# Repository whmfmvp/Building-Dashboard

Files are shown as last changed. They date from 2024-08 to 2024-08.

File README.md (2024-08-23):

<h1>Move to Net Zero: A Physical Dashboard for Net Zero Carbon Buildings</h1>  
<div align="center">
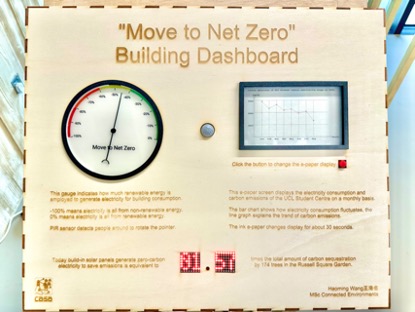
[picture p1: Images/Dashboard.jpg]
Dashboard Image

<p>Figure 1. Physical Building Dashboard</p>
</div>

<h2>Introduction</h2>
At the 2015 United Nations Climate Conference, 195 countries committed to the Paris Agreement's climate target, aiming for net zero carbon emissions. Buildings contribute significantly to global carbon emissions, making Net Zero Carbon Buildings (NZCB) a critical area in achieving this target. To raise public awareness of the importance of NZCB and to help users understand the journey toward achieving net zero in buildings, this project introduces the "Move to Net Zero" physical building dashboard.  

This dashboard serves as an interactive tool to promote the concept of NZCB, encouraging users to engage in daily actions that reduce carbon emissions. By leveraging IoT technology, the dashboard provides real-time data on electricity consumption, carbon emissions, and solar energy usage, offering users valuable insights into the building's environmental impact.  

<h2>Research Question</h2>  
This project seeks to answer the question: How can a physical dashboard displaying real-time data related to carbon neutrality effectively enhance communication and foster net-zero practices among the general public?  

<h2>Key Features</h2>   
<div align="center">
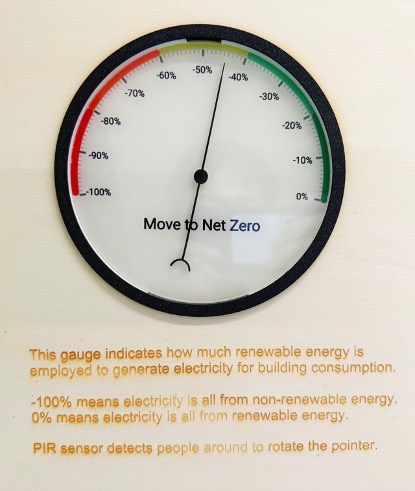
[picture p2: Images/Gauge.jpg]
Gauge Image

<p>Figure 2. Gauge</p>
</div>  

1. Real-time Data Visualization: The dashboard showcases the building's contribution to the environment, focusing on electricity consumption, carbon emissions, and solar energy usage.  
<div align="center">
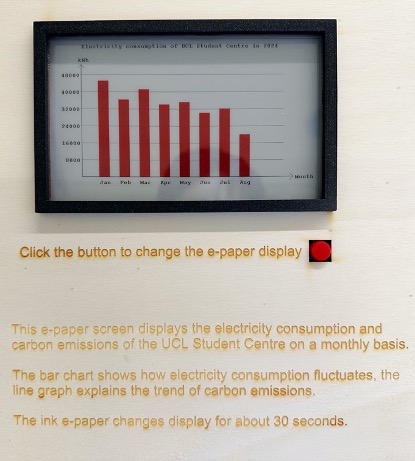
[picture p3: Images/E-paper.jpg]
E-paper Image

<p>Figure 3. E-paper</p>
</div>  

2. Interactive Design: Equipped with PIR sensors and buttons, the dashboard interacts with users by sensing their movements and actions.  
  
<div align="center">
Dot_matrix module Image
<p>Figure 4. Dot_matrix module</p>
</div>  

3. Data Visualization Tools: The dashboard utilizes gauge displays, e-paper, and a dot matrix module to communicate information in an accessible and engaging manner.  
IoT Integration: The system is powered by ESP32 microcontrollers, ensuring efficient data processing and real-time updates.  

<h2>Case Study: UCL Student Centre</h2>  
The project includes a case study of the UCL Student Centre, analyzing its electricity consumption and carbon emissions over the past two years. The findings indicate significant progress toward NZCB, with nearly 50% of the building's electricity now sourced from renewable energy.  

<h2>User Feedback</h2>  
A survey of 32 users who interacted with the dashboard revealed that the device successfully communicates key information about the building's energy usage and carbon footprint. However, it also highlighted the need for more intuitive content presentation to make the data easier to understand.  

<h2>Future Work</h2>  
Future iterations of the "Move to Net Zero" dashboard will focus on:  

1. Enriching Energy Information: Providing more comprehensive data about the building's energy use.  

2. Improving User Experience: Simplifying the dashboard's interface to make it more user-friendly and accessible.  
   
3. Add ultrasonic sensors: Counting users more precisely and collect avarage usage time for further research.

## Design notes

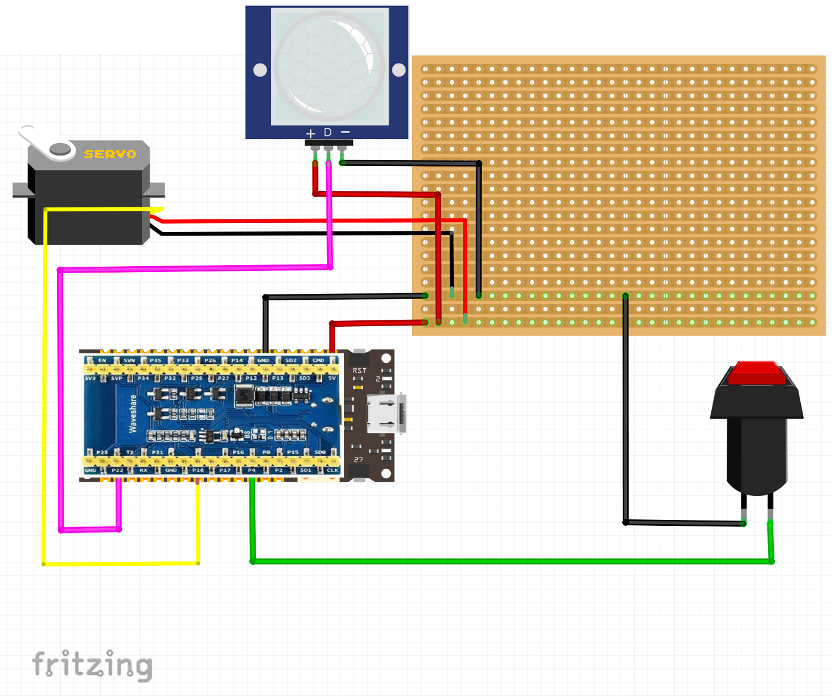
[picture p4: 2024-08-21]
Schematic/ESP32_1_back.png

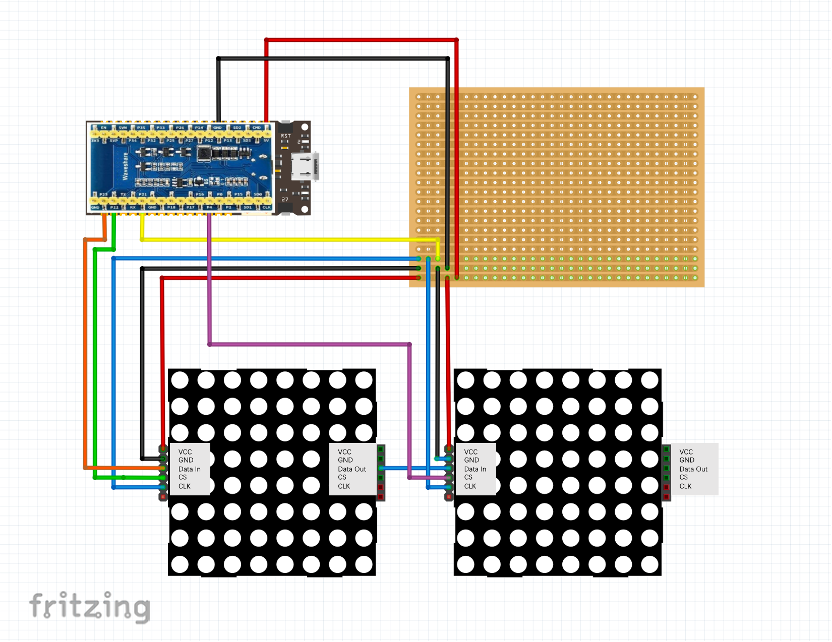
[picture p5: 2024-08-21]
Schematic/ESP32_2.png

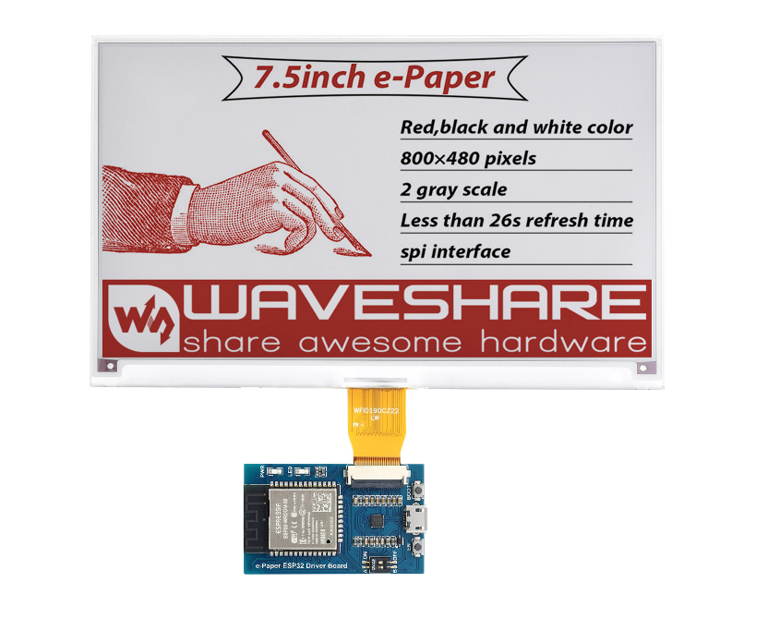
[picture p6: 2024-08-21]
Schematic/ESP32_1_front.png

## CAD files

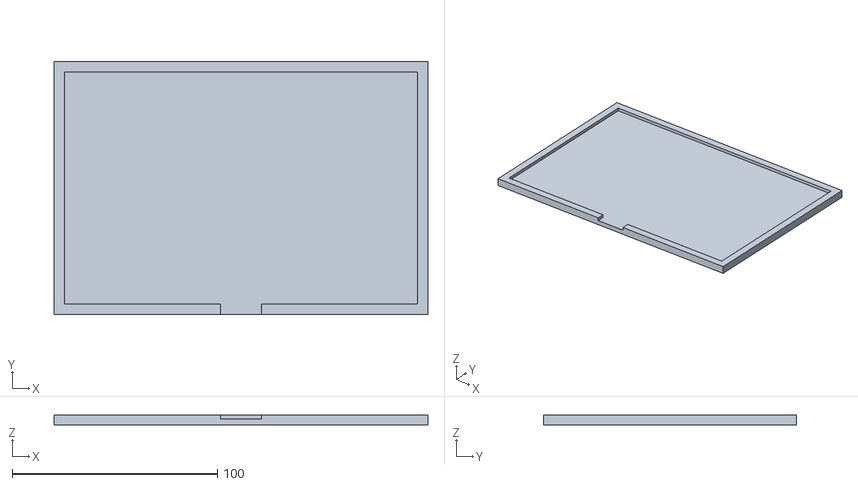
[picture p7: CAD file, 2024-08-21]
3D print/E-paper-back-frame.stl
182.2 x 123.2 x 5.00

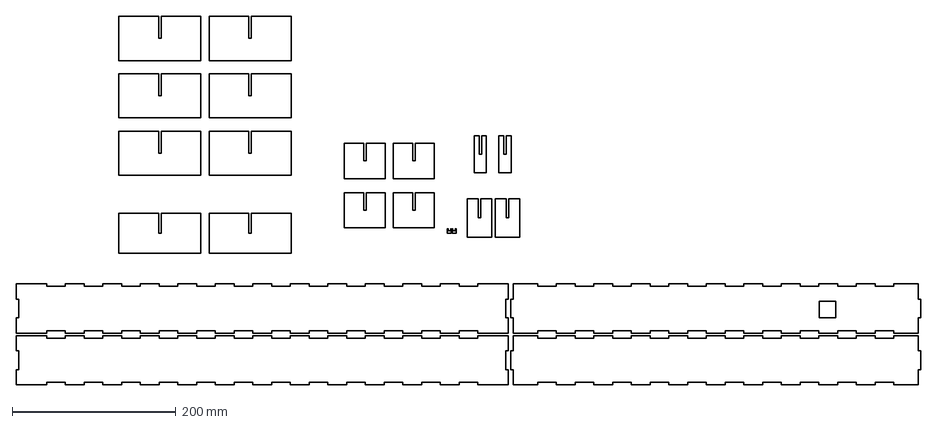
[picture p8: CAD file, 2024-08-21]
Laser cut/Underprop in the enclosure.dxf
1103.0 x 449.5 mm

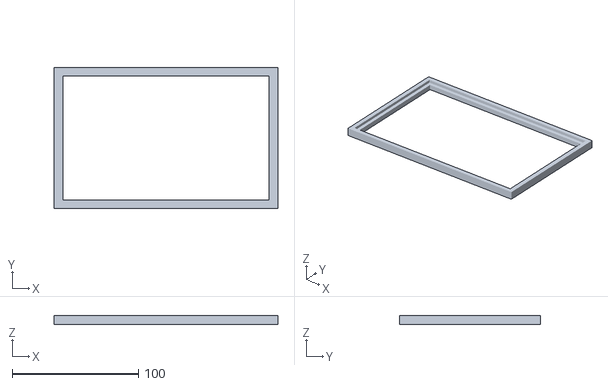
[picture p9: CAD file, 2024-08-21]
3D print/E-paper-front-frame.stl
177.2 x 111.9 x 7.00

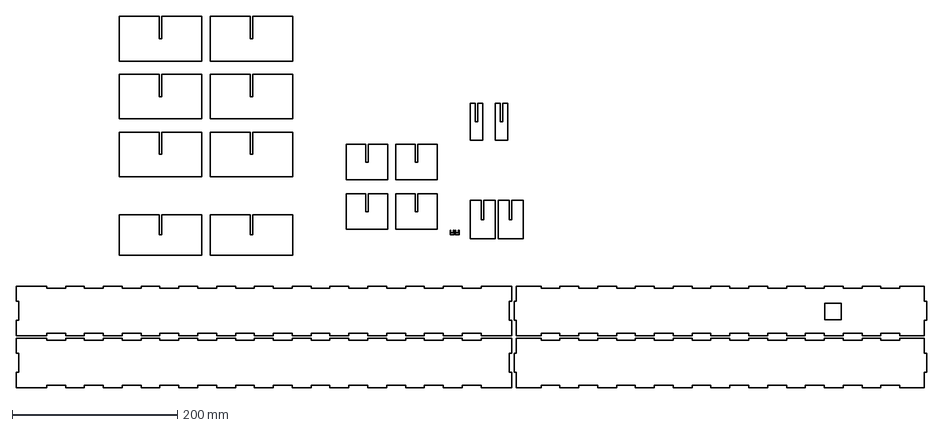
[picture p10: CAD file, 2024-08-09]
Laser cut/underprop.dxf
1103.0 x 449.5 mm

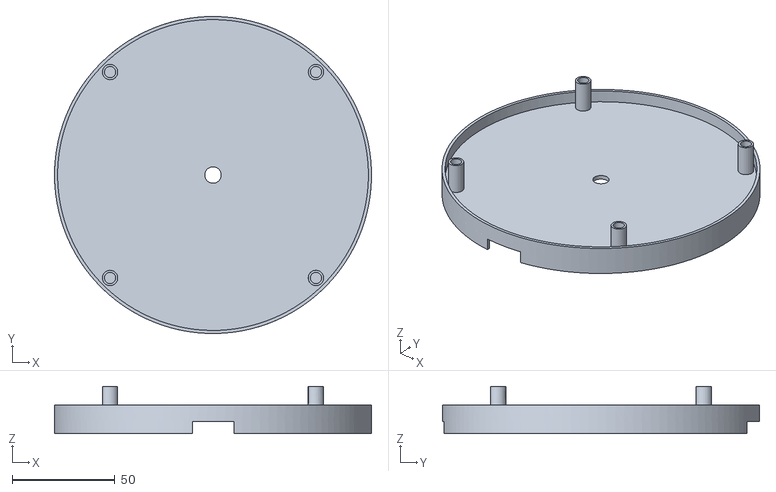
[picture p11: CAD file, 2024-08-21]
3D print/Gauge_middle.stl
154.0 x 154.0 x 23.0

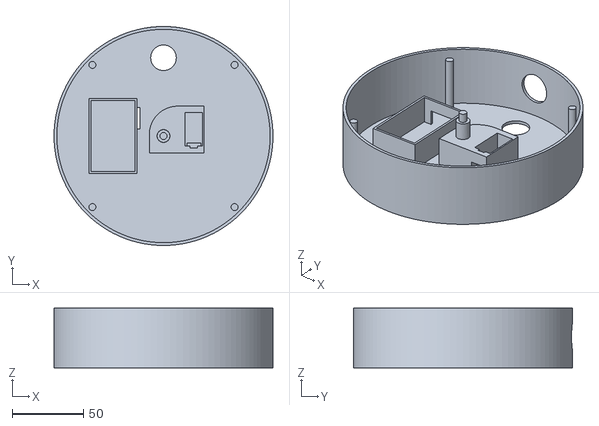
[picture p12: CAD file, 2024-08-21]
3D print/Gauge_house.stl
154.0 x 154.0 x 42.0

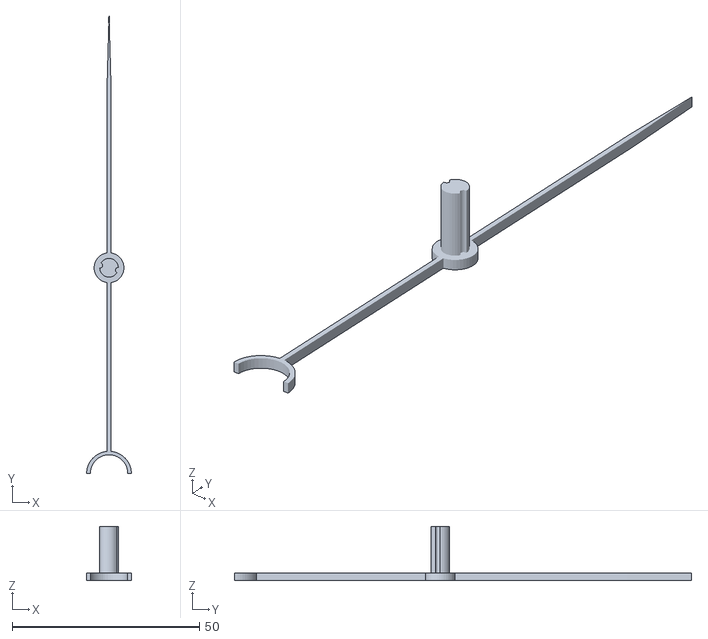
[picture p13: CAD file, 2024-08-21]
3D print/Pointer.stl
12.0 x 122.2 x 14.5

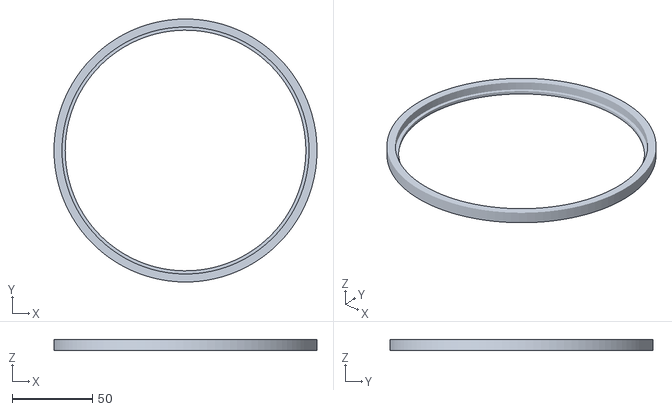
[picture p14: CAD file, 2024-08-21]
3D print/Gauge_top.stl
164.0 x 164.0 x 7.00

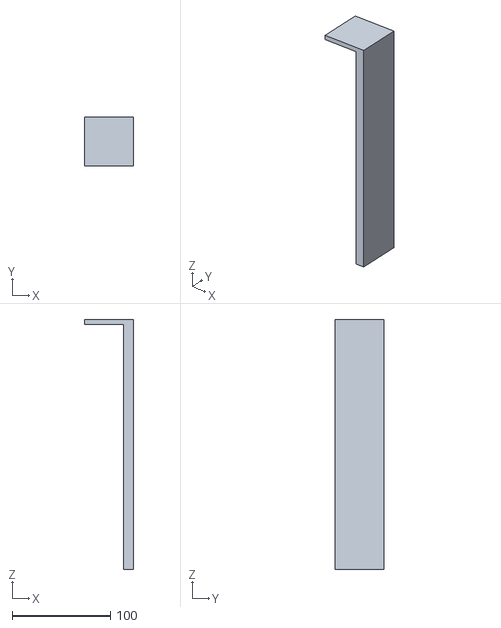
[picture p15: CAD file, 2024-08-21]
3D print/Support in the enclosure.stl
50.0 x 50.0 x 255.0

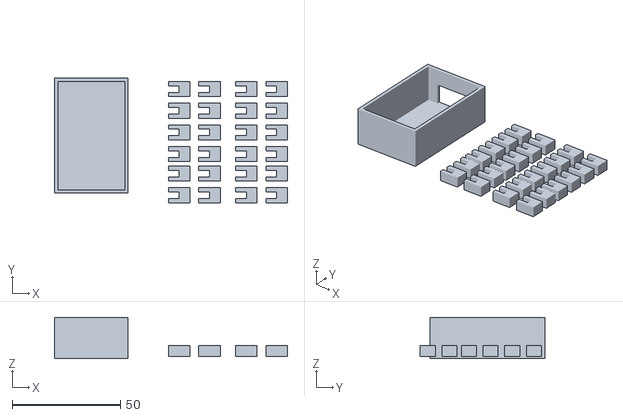
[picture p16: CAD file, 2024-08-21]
3D print/ESP32 house.stl
107.5 x 57.5 x 19.0

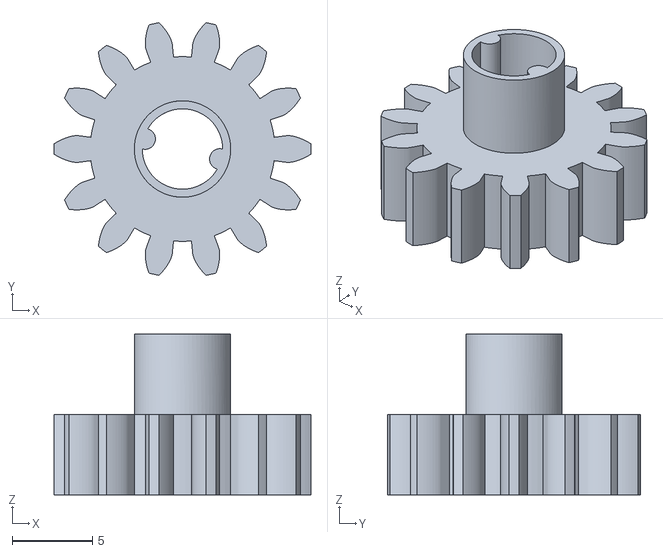
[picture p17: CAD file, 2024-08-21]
3D print/Small gear.stl
16.0 x 15.7 x 10.0

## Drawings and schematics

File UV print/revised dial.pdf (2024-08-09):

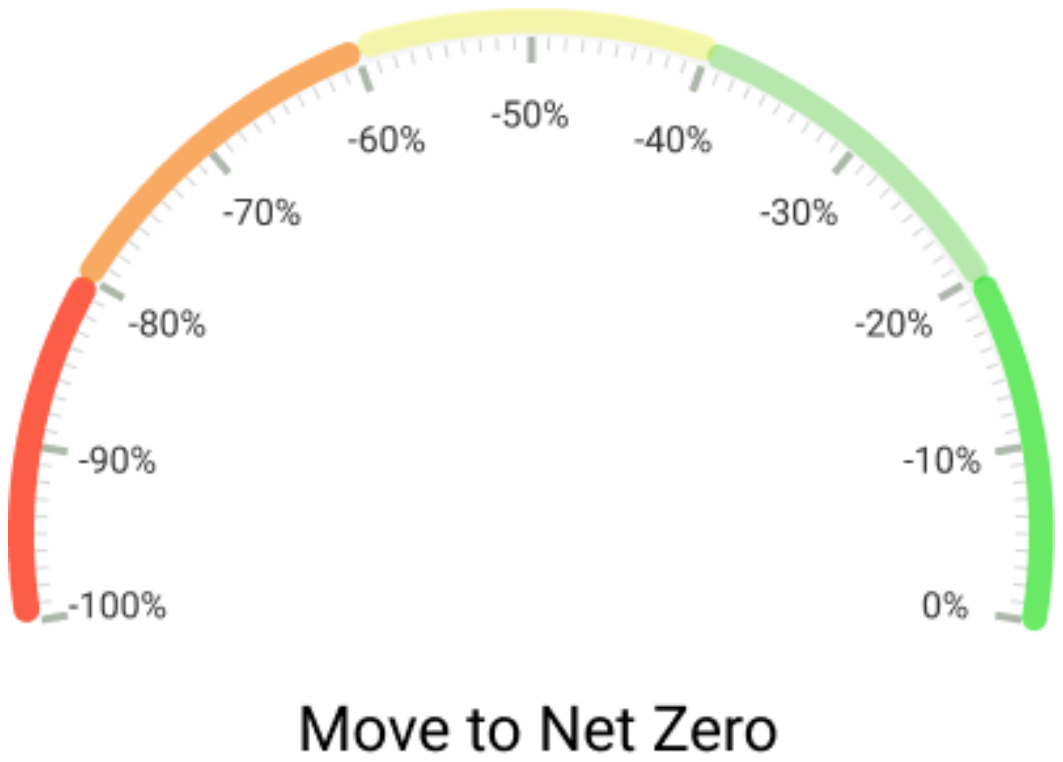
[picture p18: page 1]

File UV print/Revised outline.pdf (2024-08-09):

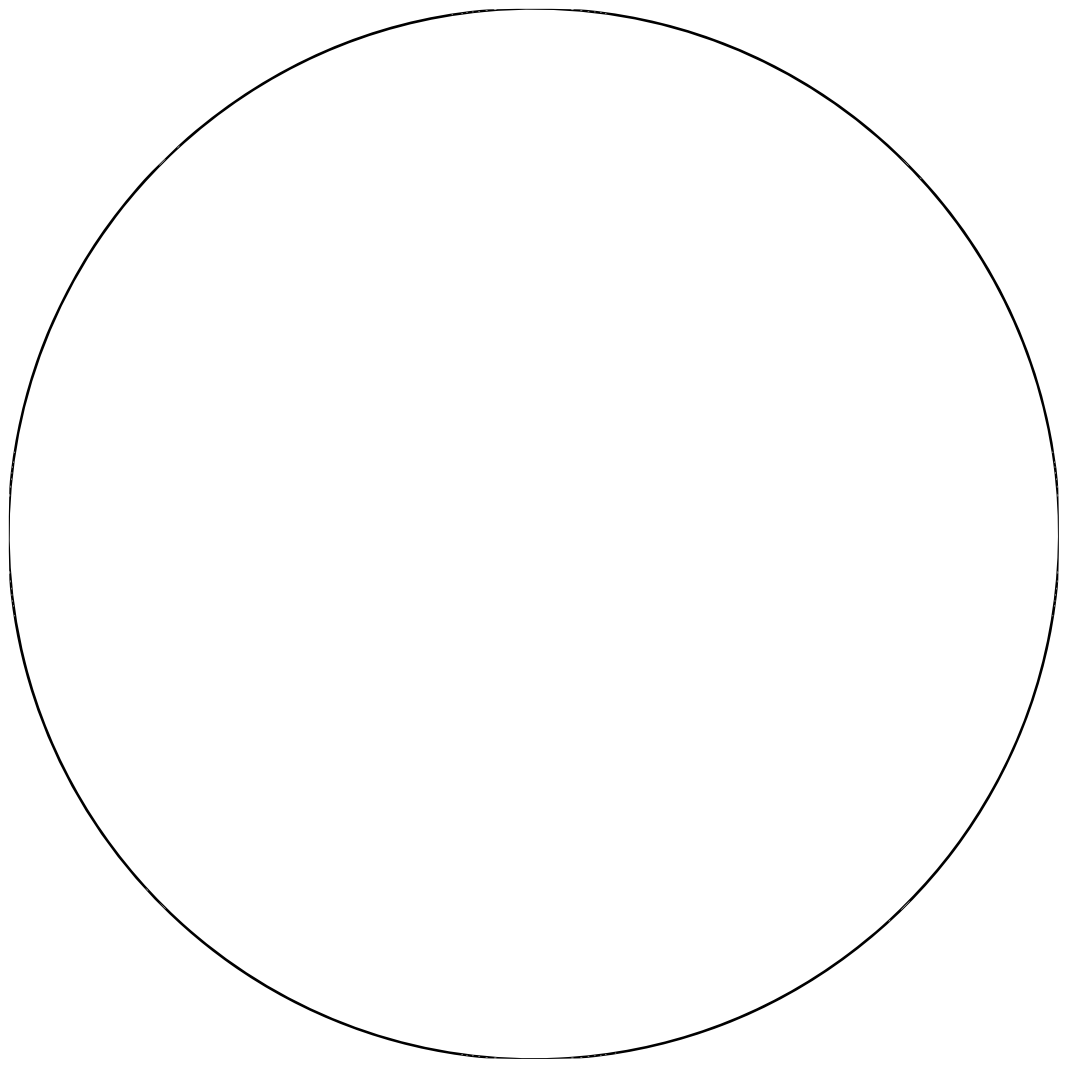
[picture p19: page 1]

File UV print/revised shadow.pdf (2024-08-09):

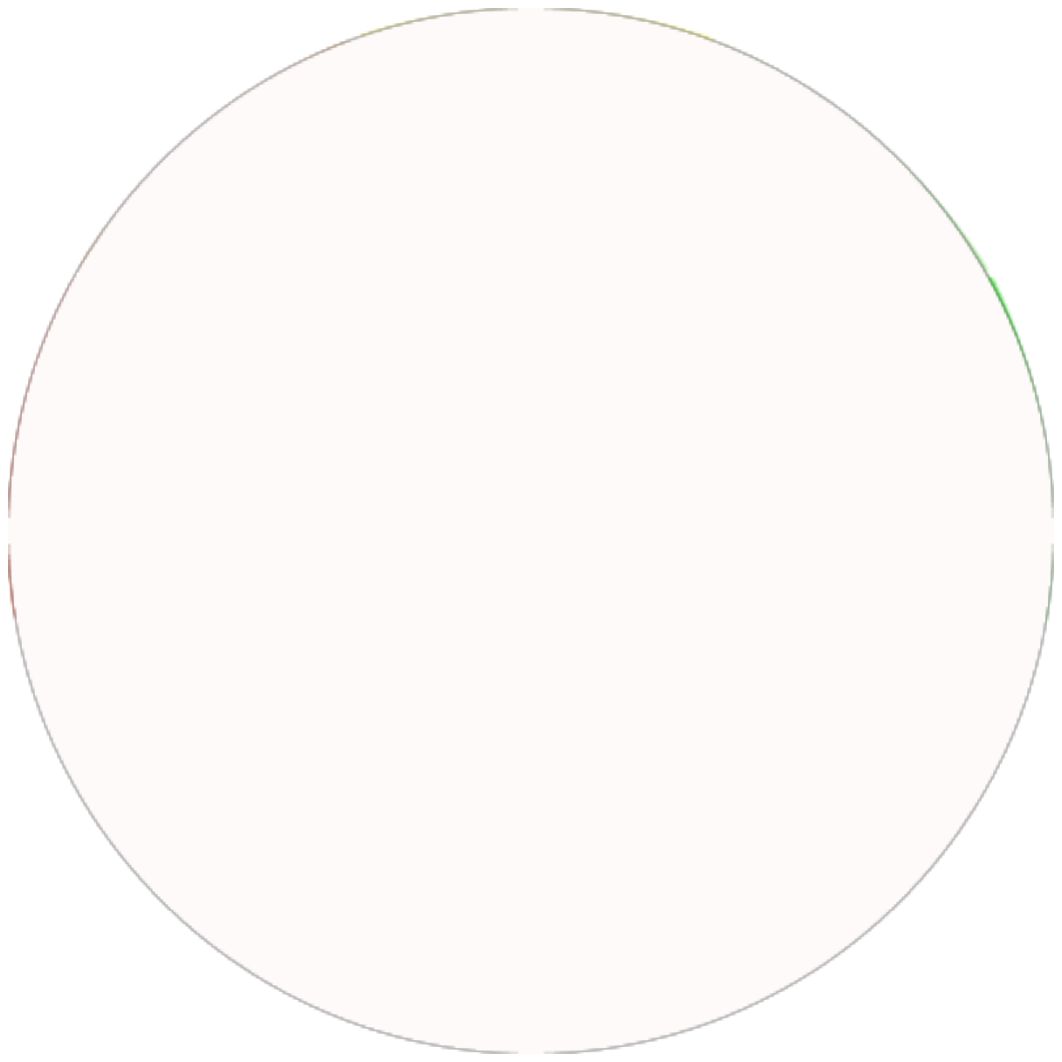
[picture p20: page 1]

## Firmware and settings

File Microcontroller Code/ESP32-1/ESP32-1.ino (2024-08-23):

#include <WiFi.h>
#include <PubSubClient.h>
#include "DEV_Config.h"
#include "EPD.h"
#include "GUI_Paint.h"
#include "imagedata.h"
#include <stdlib.h>
#include <ESP32Servo.h>
#include <NTPClient.h>
#include <WiFiUdp.h>

// Wi-Fi credentials
const char* ssid = "YOUR_WIFI";
const char* password = "YOUR_PASSWORD";

// MQTT broker parameters
const char* mqtt_server = "YOUR_MQTT";
const int mqtt_port = 1884;
const char* mqtt_username = "-";
const char* mqtt_password = "-";
const char* mqtt_topic_base_electricity = "student/CASA0022/zczqhw8/Electricity/";
const char* mqtt_topic_base_carbon = "student/CASA0022/zczqhw8/Carbon_Emissions/";
const char* mqtt_topic_servo = "student/CASA0022/zczqhw8/Net_zero_ratio"; 
const char* mqtt_topic_pir = "student/CASA0022/zczqhw8/PIR"; 
const char* mqtt_topic_button = "student/CASA0022/zczqhw8/Button";


WiFiClient espClient;
PubSubClient client(espClient);
Servo servoMotor;

int yCoordsElectricity[8] = {400, 400, 400, 400, 400, 400, 400, 400};
int yCoordsCarbon[8] = {400, 400, 400, 400, 400, 400, 400, 400};
bool dataReceivedElectricity[8] = {false, false, false, false, false, false, false, false};
bool dataReceivedCarbon[8] = {false, false, false, false, false, false, false, false};

UBYTE *BlackImage, *RYImage;
bool updateDisplay = false;
int receivedCountElectricity = 0;
int receivedCountCarbon = 0;
bool displayBarChart = true; 

const int buttonPin = 4; 
const int servoPin = 18;
const int pirPin = 22;    
int targetServoAngle = 0; 
const int servoRestAngle = 0; 

unsigned long lastPIRCheck = 0;  
const long PIRInterval = 2000;   
bool servoActive = false;        
unsigned long servoActivationTime = 0;  

int servoTurnCount = 0;          
int buttonPressCount = 0;        
unsigned long lastMidnightCheck = 0; 

bool lastButtonState = HIGH;      
unsigned long lastDebounceTime = 0; 
const long debounceDelay = 50;    

// NTP Client
WiFiUDP ntpUDP;
NTPClient timeClient(ntpUDP, "pool.ntp.org", 0, 60000); 

void setup() {
  Serial.begin(115200);
  Serial.println("EPD_7IN5B_V2_test Demo");

  // Initialize Wi-Fi
  setup_wifi();

  // Initialize MQTT
  client.setServer(mqtt_server, mqtt_port);
  client.setCallback(mqtt_callback);

  // Initialize button
  pinMode(buttonPin, INPUT_PULLUP); 

  pinMode(pirPin, INPUT); 
  servoMotor.attach(servoPin); 

  // Initialize e-Paper display
  DEV_Module_Init();

  // Attach servo
  ESP32PWM::allocateTimer(0); 
  servoMotor.setPeriodHertz(50); 
  servoMotor.attach(servoPin, 500, 2400); 

    // Initialize NTP
  timeClient.begin();

  Serial.println("e-Paper Init and Clear...");
  EPD_7IN5B_V2_Init();
  EPD_7IN5B_V2_Clear();
  DEV_Delay_ms(500);

  // Create image cache
  UWORD Imagesize = ((EPD_7IN5B_V2_WIDTH % 8 == 0) ? (EPD_7IN5B_V2_WIDTH / 8) : (EPD_7IN5B_V2_WIDTH / 8 + 1)) * EPD_7IN5B_V2_HEIGHT;

  if ((BlackImage = (UBYTE *)malloc(Imagesize)) == NULL) {
    Serial.println("Failed to apply for black memory...");
    while(1);
  }
  if ((RYImage = (UBYTE *)malloc(Imagesize)) == NULL) {
    Serial.println("Failed to apply for red memory...");
    while(1);
  }
  Serial.println("NewImage: BlackImage and RYImage");
  Paint_NewImage(BlackImage, EPD_7IN5B_V2_WIDTH, EPD_7IN5B_V2_HEIGHT, 0, WHITE);
  Paint_NewImage(RYImage, EPD_7IN5B_V2_WIDTH, EPD_7IN5B_V2_HEIGHT, 0, WHITE);

  // Clear image cache
  Paint_SelectImage(BlackImage);
  Paint_Clear(WHITE);
  Paint_SelectImage(RYImage);
  Paint_Clear(WHITE);

  // Draw initial image
  drawImage(BlackImage, RYImage, displayBarChart);
}
void loop() {
  if (!client.connected()) {
    reconnect();
  }
  client.loop();

  unsigned long currentMillis = millis();
  timeClient.update(); 

  if (currentMillis - lastMidnightCheck >= 60000) {
    lastMidnightCheck = currentMillis;
    if (timeClient.getHours() == 0 && timeClient.getMinutes() == 0) {
      servoTurnCount = 0; 
      buttonPressCount = 0; 
      Serial.println("Servo turn count and button press count reset to 0 at midnight.");
    }
  }

  if (currentMillis - lastPIRCheck >= PIRInterval) {
    lastPIRCheck = currentMillis; 
    int pirState = digitalRead(pirPin);
    if (pirState == HIGH && !servoActive) {
      servoMotor.write(targetServoAngle);
      servoActivationTime = currentMillis;
      servoActive = true;
      servoTurnCount++; 
      client.publish(mqtt_topic_pir, String(servoTurnCount).c_str()); 
      Serial.print("Motion detected - Servo moving to target angle. Turn count: ");
      Serial.println(servoTurnCount);
    }
  }

  if (servoActive && (millis() - servoActivationTime >= 10000)) {
    servoMotor.write(servoRestAngle);
    servoActive = false;
    Serial.println("Servo moving back to rest position after delay.");
  }

  int reading = digitalRead(buttonPin);
  if (reading != lastButtonState) {
    lastDebounceTime = currentMillis; 
  }

  lastButtonState = reading; 

  if (updateDisplay) {
    drawImage(BlackImage, RYImage, displayBarChart);
    updateDisplay = false;
  }

  if (digitalRead(buttonPin) == HIGH) {
    delay(50); 
    while (digitalRead(buttonPin) == HIGH); 
    buttonPressCount++; 
    client.publish(mqtt_topic_button, String(buttonPressCount).c_str()); 
    Serial.print("Button pressed. Press count: ");
    Serial.println(buttonPressCount);
    displayBarChart = !displayBarChart; 
    drawImage(BlackImage, RYImage, displayBarChart);
    updateDisplay = true; 
  }
}

void setup_wifi() {
  delay(10);
  Serial.println();
  Serial.print("Connecting to ");
  Serial.println(ssid);

  WiFi.begin(ssid, password);

  while (WiFi.status() != WL_CONNECTED) {
    delay(500);
    Serial.print(".");
  }

  Serial.println("");
  Serial.println("WiFi connected");
  Serial.println("IP address: ");
  Serial.println(WiFi.localIP());
}

void reconnect() {
  while (!client.connected()) {
    Serial.print("Attempting MQTT connection...");
    if (client.connect("ESP32Client", mqtt_username, mqtt_password)) {
      Serial.println("connected");

      for (int i = 1; i <= 8; i++) {
        String topic = String(mqtt_topic_base_electricity) + "2024-" + (i < 10 ? "0" : "") + String(i);
        client.subscribe(topic.c_str());
        String topicCarbon = String(mqtt_topic_base_carbon) + "2024-" + (i < 10 ? "0" : "") + String(i);
        client.subscribe(topicCarbon.c_str());
      }
      client.subscribe(mqtt_topic_servo);
    } else {
      Serial.print("failed, rc=");
      Serial.print(client.state());
      Serial.println(" try again in 5 seconds");
      delay(5000);
    }
  }
}

void mqtt_callback(char* topic, byte* payload, unsigned int length) {
  payload[length] = '\0';
  String message = String((char*)payload);
  float value = atof(message.c_str()); 
  Serial.print("Message arrived [");
  Serial.print(topic);
  Serial.print("] ");
  Serial.println(value);

  if (String(topic) == mqtt_topic_servo) {
      targetServoAngle = int(value * 100); 
      targetServoAngle = constrain(targetServoAngle, 0, 180); 
    }

  int index = atof(&topic[strlen(topic) - 2]) - 1;  
  
  if (strstr(topic, "Electricity")) {
    yCoordsElectricity[index] = map(value, 0, 48000, 400, 100);
    dataReceivedElectricity[index] = true;
    receivedCountElectricity++;
  } else if (strstr(topic, "Carbon_Emissions")) {
    yCoordsCarbon[index] = map(value, 0, 9000, 400, 100);
    dataReceivedCarbon[index] = true;
    receivedCountCarbon++;
  }

  if (receivedCountElectricity == 8 && receivedCountCarbon == 8) {
    updateDisplay = true;
  }
}


void drawImage(UBYTE *BlackImage, UBYTE *RYImage, bool displayBarChart) {
  Paint_SelectImage(BlackImage);
  Paint_Clear(WHITE);
  Paint_DrawPoint(100, 400, BLACK, DOT_PIXEL_1X1, DOT_STYLE_DFT);
  Paint_DrawLine(100, 400, 100, 70, BLACK, DOT_PIXEL_1X1, LINE_STYLE_SOLID);
  Paint_DrawLine(100, 400, 730, 400, BLACK, DOT_PIXEL_1X1, LINE_STYLE_SOLID);
  Paint_DrawLine(110, 80, 100, 70, BLACK, DOT_PIXEL_1X1, LINE_STYLE_SOLID);
  Paint_DrawLine(90, 80, 100, 70, BLACK, DOT_PIXEL_1X1, LINE_STYLE_SOLID);
  Paint_DrawLine(720, 390, 730, 400, BLACK, DOT_PIXEL_1X1, LINE_STYLE_SOLID);
  Paint_DrawLine(720, 410, 730, 400, BLACK, DOT_PIXEL_1X1, LINE_STYLE_SOLID);

  Paint_DrawString_EN(150, 410, "Jan", &Font16, WHITE, BLACK);
  Paint_DrawString_EN(210, 410, "Feb", &Font16, WHITE, BLACK);
  Paint_DrawString_EN(270, 410, "Mar", &Font16, WHITE, BLACK);
  Paint_DrawString_EN(330, 410, "Apr", &Font16, WHITE, BLACK);
  Paint_DrawString_EN(390, 410, "May", &Font16, WHITE, BLACK);
  Paint_DrawString_EN(450, 410, "Jun", &Font16, WHITE, BLACK);
  Paint_DrawString_EN(510, 410, "Jul", &Font16, WHITE, BLACK);
  Paint_DrawString_EN(570, 410, "Aug", &Font16, WHITE, BLACK);


  if (displayBarChart) {
    Paint_DrawLine(100, 350, 700, 350, BLACK, DOT_PIXEL_1X1, LINE_STYLE_DOTTED);
    Paint_DrawLine(100, 300, 700, 300, BLACK, DOT_PIXEL_1X1, LINE_STYLE_DOTTED);
    Paint_DrawLine(100, 250, 700, 250, BLACK, DOT_PIXEL_1X1, LINE_STYLE_DOTTED);
    Paint_DrawLine(100, 200, 700, 200, BLACK, DOT_PIXEL_1X1, LINE_STYLE_DOTTED);
    Paint_DrawLine(100, 150, 700, 150, BLACK, DOT_PIXEL_1X1, LINE_STYLE_DOTTED);
    Paint_DrawLine(100, 100, 700, 100, BLACK, DOT_PIXEL_1X1, LINE_STYLE_DOTTED);
    Paint_DrawString_EN(100, 10, "Electricity consumption of UCL Student Centre in 2024", &Font16, WHITE, BLACK);
    Paint_DrawNum(50, 345, 8000, &Font16, BLACK, WHITE);
    Paint_DrawNum(40, 295, 16000, &Font16, BLACK, WHITE);
    Paint_DrawNum(40, 245, 24000, &Font16, BLACK, WHITE);
    Paint_DrawNum(40, 195, 32000, &Font16, BLACK, WHITE);
    Paint_DrawNum(40, 145, 40000, &Font16, BLACK, WHITE);
    Paint_DrawNum(40, 95, 48000, &Font16, BLACK, WHITE);

    Paint_DrawString_EN(90, 50, "kWh", &Font16, WHITE, BLACK);
    Paint_DrawString_EN(735, 395, "Month", &Font16, WHITE, BLACK);
    // Draw bar chart
      Paint_SelectImage(RYImage);
      Paint_Clear(WHITE);
    for (int i = 0; i < 8; i++) {
      Paint_DrawRectangle(150 + i * 60, yCoordsElectricity[i], 180 + i * 60, 400, BLACK, DOT_PIXEL_1X1, DRAW_FILL_FULL);
    }
  } else {
    Paint_DrawString_EN(50, 10, "Carbon emissions of UCL Student Centre electricity usage in 2024", &Font16, WHITE, BLACK);

    Paint_DrawLine(100, 100, 700, 100, BLACK, DOT_PIXEL_1X1, LINE_STYLE_DOTTED);
    Paint_DrawLine(100, 200, 700, 200, BLACK, DOT_PIXEL_1X1, LINE_STYLE_DOTTED);
    Paint_DrawLine(100, 300, 700, 300, BLACK, DOT_PIXEL_1X1, LINE_STYLE_DOTTED);
    Paint_DrawLine(165, 400, 165, 100, BLACK, DOT_PIXEL_1X1, LINE_STYLE_DOTTED);
    Paint_DrawLine(225, 400, 225, 100, BLACK, DOT_PIXEL_1X1, LINE_STYLE_DOTTED);
    Paint_DrawLine(285, 400, 285, 100, BLACK, DOT_PIXEL_1X1, LINE_STYLE_DOTTED);
    Paint_DrawLine(345, 400, 345, 100, BLACK, DOT_PIXEL_1X1, LINE_STYLE_DOTTED);
    Paint_DrawLine(405, 400, 405, 100, BLACK, DOT_PIXEL_1X1, LINE_STYLE_DOTTED);
    Paint_DrawLine(465, 400, 465, 100, BLACK, DOT_PIXEL_1X1, LINE_STYLE_DOTTED);
    Paint_DrawLine(525, 400, 525, 100, BLACK, DOT_PIXEL_1X1, LINE_STYLE_DOTTED);
    Paint_DrawLine(585, 400, 585, 100, BLACK, DOT_PIXEL_1X1, LINE_STYLE_DOTTED);
    Paint_DrawNum(50, 300, 3000, &Font16, BLACK, WHITE);
    Paint_DrawNum(50, 200, 6000, &Font16, BLACK, WHITE);
    Paint_DrawNum(50, 100, 9000, &Font16, BLACK, WHITE);

    Paint_DrawString_EN(90, 50, "kgCO2", &Font16, WHITE, BLACK);
    Paint_DrawString_EN(735, 395, "Month", &Font16, WHITE, BLACK);
    // Draw line chart
      Paint_SelectImage(RYImage);
      Paint_Clear(WHITE);
    for (int i = 0; i < 8; i++) {
      Paint_DrawPoint(165 + i * 60, yCoordsCarbon[i], BLACK, DOT_PIXEL_3X3, DOT_STYLE_DFT);
      if (i < 7) {
        Paint_DrawLine(165 + i * 60, yCoordsCarbon[i], 165 + (i + 1) * 60, yCoordsCarbon[i + 1], BLACK, DOT_PIXEL_1X1, LINE_STYLE_SOLID);
      }
    }
  }

  Serial.println("EPD_Display");
  EPD_7IN5B_V2_Display(BlackImage, RYImage);
  DEV_Delay_ms(2000);
}

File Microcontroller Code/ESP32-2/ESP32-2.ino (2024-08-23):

#include <WiFi.h>
#include <PubSubClient.h>
#include <MD_MAX72xx.h>
#include <SPI.h>

#define HARDWARE_TYPE MD_MAX72XX::FC16_HW
#define MAX_DEVICES 2

#define CLK_PIN   21  
#define DATA_PIN  23  
#define CS_PIN1    22  
#define CS_PIN2    4   


MD_MAX72XX mx1(HARDWARE_TYPE, DATA_PIN, CLK_PIN, CS_PIN1, 1);
MD_MAX72XX mx2(HARDWARE_TYPE, DATA_PIN, CLK_PIN, CS_PIN2, 1);

const char* ssid = "YOUR_WIFI";
const char* password = "YOUR_PASSWORD";
const char* mqtt_server = "YOUR_MQTT_SERVER";
const int mqtt_port = 1884;
const char* mqtt_username = "-";
const char* mqtt_password = "-";
const char* mqtt_topic_base = "student/CASA0022/zczqhw8/Dot_matrix";

WiFiClient espClient;
PubSubClient client(espClient);
int integerToShow = 0;   
int decimalToShow = 0;   

void setup() {
  Serial.begin(115200);
  setupWiFi();
  setupMQTT();
  mx1.begin();
  mx1.control(MD_MAX72XX::INTENSITY, 8);
  mx1.clear();
  mx2.begin();
  mx2.control(MD_MAX72XX::INTENSITY, 8);
  mx2.clear();
}


void loop() {
  if (!client.connected()) {
    reconnectMQTT();
  }
  client.loop();

  displayTwoDigits(integerToShow, 0);  
  displayTwoDigits(decimalToShow, 1);  
  delay(2000);  
}

void setupWiFi() {
  Serial.println("Connecting to WiFi...");
  WiFi.begin(ssid, password);
  while (WiFi.status() != WL_CONNECTED) {
    delay(500);
    Serial.print(".");
  }
  Serial.println("WiFi connected");
}

void setupMQTT() {
  client.setServer(mqtt_server, mqtt_port);
  client.setCallback(mqttCallback);
  reconnectMQTT();
}

void reconnectMQTT() {
  while (!client.connected()) {
    Serial.println("Connecting to MQTT...");
    if (client.connect("ESP32Client", mqtt_username, mqtt_password)) {
      Serial.println("Connected");
      client.subscribe(mqtt_topic_base);
    } else {
      Serial.print("Failed, rc=");
      Serial.print(client.state());
      delay(5000);
    }
  }
}

void mqttCallback(char* topic, byte* payload, unsigned int length) {
  Serial.print("Message received [");
  Serial.print(topic);
  Serial.print("] ");
  String message;
  for (int i = 0; i < length; i++) {
    message += (char)payload[i];
  }
  Serial.println(message);

  float num = message.toFloat();
  integerToShow = int(num);           
  decimalToShow = int(num * 100) % 100;  
  Serial.print("Parsed decimal part: ");
  Serial.println(decimalToShow);
}

void displayTwoDigits(int number, int screen) {
  MD_MAX72XX* mx = (screen == 0) ? &mx1 : &mx2;  
  if (number < 0 || number > 99) return;  

  int tens = number / 10;  
  int units = number % 10;  

  mx->clear();
  displayDigit(*mx, tens, 0);  
  displayDigit(*mx, units, 4);  
}

void displayDigit(MD_MAX72XX& mx, int digit, int offset) {
  const uint8_t digits[10][4] = {
    {0x3E, 0x45, 0x49, 0x3E}, 
    {0x00, 0x42, 0x7F, 0x40}, 
    {0x72, 0x49, 0x49, 0x46}, 
    {0x21, 0x49, 0x49, 0x36}, 
    {0x0F, 0x08, 0x08, 0x7F}, 
    {0x4F, 0x49, 0x49, 0x31}, 
    {0x3E, 0x49, 0x49, 0x32}, 
    {0x01, 0x01, 0x79, 0x07}, 
    {0x36, 0x49, 0x49, 0x36}, 
    {0x26, 0x49, 0x49, 0x3E}  
  };

  for (int i = 0; i < 4; i++) {
    mx.setColumn(7 - (offset + i), digits[digit][i]);  
  }
}

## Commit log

2024-08-09 DXF file
    [underprop.dxf]
2024-08-21 3D print
    [E-paper-back-frame.stl, E-paper-front-frame.stl, ESP32 house.stl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]
